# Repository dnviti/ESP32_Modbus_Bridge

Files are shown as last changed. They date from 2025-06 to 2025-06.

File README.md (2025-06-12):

# **Dual ESP32 Modbus TCP to Wi-Fi Bridge**

This repository contains the KiCad project files and design documentation for a custom PCB that acts as an industrial data bridge. The board reads data from a PLC via Modbus TCP over Ethernet and transmits it to a web server via Wi-Fi.

## **High-Level Functionality**

The board is designed around a dual-ESP32 architecture to handle network tasks concurrently and without interference:

* **ESP32 \#1 (Modbus Master):**  
  * Connects to an industrial network via a hardwired Ethernet (RJ45) port.  
  * Communicates with a PLC using the Modbus TCP protocol to read register values.  
  * Transfers the retrieved data internally to the second ESP32.  
* **ESP32 \#2 (Web Client):**  
  * Receives data from the first ESP32 via a high-speed UART link.  
  * Connects to a local Wi-Fi network.  
  * Formats and sends the data to a specified web server endpoint using HTTPS POST requests.  
  * Drives a small I2C OLED display for real-time status monitoring (e.g., IP address, connection status, last sync time).

## **Key Hardware Features**

* **Dual ESP32-WROOM-32D Sockets:** For parallel processing of networking tasks.  
* **Robust Power Supply:** On-board 24V to 3.3V DC-DC buck converter to draw power directly from a PLC or industrial power rail.  
* **Wired & Wireless Connectivity:** Features a Hanrun HR911105A RJ45 port for Ethernet and integrated Wi-Fi/Bluetooth on the ESP32s.  
* **On-Board Debugging:** Includes FTDI programming headers, manual boot/reset buttons, and debug jumpers with status LEDs for each ESP32.  
* **I/O & Expansion:** Provides breakout headers for unused GPIO pins for future expansion and an I2C header for the status display.  
* **High-Density Design:** Utilizes 0402 package size for passive components to maintain a small form factor.

## **Full Documentation**

This README provides a brief overview. For complete technical details, including the full schematic specification, component list, bill of materials (BOM), and PCB layout guidelines, please refer to the comprehensive design document:

➡️ View the Complete Design & Manufacturing Specification  
(Note: Replace the link above with the actual URL to your hosted specification document.)

## **Project Files**

* **/Hardware**: Contains the KiCad project files (.pro, .sch, .kicad\_pcb).  
* **/Documentation**: Contains the full design specification PDF and other supporting documents.  
* **/Firmware**: Contains example Arduino/ESP-IDF source code for both ESP32 modules.  
* **/Gerbers**: Contains the final manufacturing files for PCB fabrication.

*This project is designed for industrial applications where reliability and clear diagnostics are critical. Please review the full documentation before fabrication or assembly.*

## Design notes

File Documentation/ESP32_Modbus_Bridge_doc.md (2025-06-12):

# **Complete Design & Manufacturing Specification: Dual ESP32 Modbus-Wi-Fi Bridge**

Document Version: 2.3  
Date: June 12, 2025  
Project Revision: 0.1

## **1\. Schematic Design Specification**

This document provides the detailed, step-by-step connection instructions for creating the complete schematic for the Dual ESP32 Modbus-Wi-Fi Bridge, based on project revision 0.1.

### **1.1. Footprint Assignment**

Before proceeding to PCB layout, every component listed below must be assigned a correct physical footprint in the EDA software. An incorrect footprint will result in a board that cannot be assembled. The recommended footprints are provided for each component.

### **1.2. Part 1: Shared Board Components (The Foundation)**

This section details the main 24V to 3.3V power supply unit that powers the entire board.

**Component List:**

* **J1:** Conn\_Screw\_Terminal\_1x02 (Footprint: TerminalBlock:TerminalBlock\_bornier-2\_P5.08mm)  
* **U3:** LM2596S-3.3 (Footprint: Package\_TO\_SOT\_SMD:TO-263-5\_TabPin3)  
* **C2:** 100uF Electrolytic Capacitor (Footprint: Capacitor\_SMD:CP\_Elec\_6.3x5.4mm, verify voltage rating \> 24V)  
* **C1:** 220uF Electrolytic Capacitor (Footprint: Capacitor\_SMD:CP\_Elec\_8x10.5mm)  
* **D1:** D\_Schottky (1N5822 SMD equivalent) (Footprint: Diode\_SMD:D\_SMA)  
* **L1:** 33uH Inductor (Footprint: Inductor\_SMD:L\_Bourns\_SRR1260, verify current rating)  
* **D2:** LED (Footprint: LED\_SMD:LED\_0603\_1608Metric)  
* **R1:** 2.2kΩ Resistor (Footprint: Resistor\_SMD:R\_0603\_1608Metric)

**Connection Instructions:**

1. **24V Input:** Connect **Pin 1** of **J1** to a net named \+24V. Connect **Pin 2** of **J1** to the main GND net.  
2. **LM2596S-3.3 Input and Control:** Connect the \+24V net to **Pin 1 (VIN)** of **U3**. Place **C2** between the \+24V net and the GND net. Connect **Pin 3 (GND)** of **U3** to the GND net. Connect **Pin 5 (ON/OFF)** of **U3** directly to the GND net.  
3. **LM2596S-3.3 Output Circuit:** Connect the **Anode** of **D1** to the GND net. Connect the **Cathode** of **D1** to **Pin 2 (VOUT)** of **U3**. Connect one end of **L1** also to **Pin 2 (VOUT)** of **U3**. Connect the other end of **L1** to a new net named \+3.3V. Place **C1** between the \+3.3V net and the GND net.  
4. **Feedback Connection:** Connect **Pin 4 (Feedback)** of **U3** directly to the \+3.3V net.  
5. **Power Indicator LED:** Connect one end of **R1** to the \+3.3V net. Connect the other end of **R1** to the **Anode** of **D2**. Connect the **Cathode** of **D2** to the GND net.

### **1.3. Part 2: ESP32 \#1 (Modbus Master & Ethernet)**

**Component List:**

* **U1:** ESP32-WROOM-32D (Footprint: RF\_Module:ESP32-WROOM-32)  
* **U5:** LAN8720A (Footprint: Package\_QFN:QFN-24-1EP\_4x4mm\_P0.5mm\_EP2.6x2.6mm)  
* **Y1:** SG-7050CAN 50MHz (Footprint: Oscillator:Oscillator\_SMD\_5032-4Pin\_5.0x3.2mm)  
* **J5:** Hanrun HR911105A (Footprint: Connector\_RJ:RJ45\_Hanrun\_HR911105A\_Horizontal)  
* **J4:** Conn\_01x06\_Male (FTDI ESP32\#1) (Footprint: Connector\_PinHeader\_2.54mm:PinHeader\_1x06\_P2.54mm\_Vertical)  
* **SW1:** SW\_Push (U1\_BOOT) (Footprint: Button\_Switch\_SMD:SW\_SPST\_PTS645)  
* **C3, C4, C5, C6, C7, C8, C9, C10, C11:** Capacitors (See schematic for values and assign footprints like C\_0402, C\_0805)  
* **R2, R3, R4, R5, R6, R8, R9:** Resistors (See schematic for values and assign footprints like R\_0402)  
* **FB1:** Ferrite\_Bead (Footprint: Inductor\_SMD:L\_0603\_1608Metric)  
* **Debug Interface Components:** See Section 1.6.1  
* **GPIO Breakout Components:** See Section 1.7.1

**Connection Instructions:**

1. **ESP32 \#1 Power and Decoupling:** Connect the **VCC** and **GND** pins of **U1** to the \+3.3V and GND nets. Place **C3 (10uF)** and **C4 (100nF)** between VCC and GND, close to the module.  
2. **ESP32 \#1 Programming Header (FTDI):** Place **J4**. Connect its **GND** to GND, **TXD** to **GPIO3** of **U1**, and **RXD** to **GPIO1** of **U1**. Leave **VCC** and **CTS** unconnected.  
3. **ESP32 \#1 Auto-Reset and Manual Boot Circuit:** Connect a **100nF capacitor** between the **DTR pin** of **J4** and the **EN** pin of **U1**. Connect **R2 (10kΩ)** between the **EN** pin and \+3.3V. Connect **SW1** between the **GPIO0** pin of **U1** and GND. Connect **R3 (10kΩ)** between the **GPIO0** pin and \+3.3V.  
4. **ESP32 \#1 Strapping Pin:** Connect **R4 (10kΩ)** between the **GPIO12** pin of **U1** and GND.  
5. **Ethernet Sub-system (LAN8720A, Oscillator, RJ45):**  
   * **Clock Generation (Y1):** Connect the **VCC pin** of **Y1** to \+3.3V and place **C11 (100nF)** between this pin and GND. Connect the **ST pin** of **Y1** to \+3.3V. Connect the **GND pin** of **Y1** to GND. Connect the **OUT pin** of **Y1** to **Pin 5 (XTAL1/CLKIN)** of **U5**.  
   * **ESP32 to LAN8720A Interface:** Connect **Pin 14 (nINT/REFCLKO)** of **U5** to **GPIO0** of **U1**. Connect **GPIO23** of **U1** to **Pin 13 (MDC)** of **U5**. Connect **GPIO18** of **U1** to **Pin 12 (MDIO)** of **U5**. For RMII Transmit: U1 GPIO21 \-\> U5 Pin 16 (TXEN); U1 GPIO19 \-\> U5 Pin 17 (TXD0); U1 GPIO22 \-\> U5 Pin 18 (TXD1). For RMII Receive: U1 GPIO25 \<- U5 Pin 8 (RXD0); U1 GPIO26 \<- U5 Pin 7 (RXD1); U1 GPIO27 \<- U5 Pin 11 (CRS\_DV).  
   * **LAN8720A (U5) Support Circuitry:** Connect **R5 (12.1kΩ)** from **Pin 24 (RBIAS)** of **U5** to GND. Place **C7 (1uF)** and **C8 (470pF)** in parallel between **Pin 6 (VDDCR)** of **U5** and GND. For analog power filtering, connect the \+3.3V net to **FB1**, creating a \+3.3V\_Filtered net. Connect this filtered net to **Pin 1 (VDD2A)** and **Pin 19 (VDD1A)** of **U5**. Place **C10 (100nF)** from VDD2A to GND, and **C6 (100nF)** from VDD1A to GND.  
   * **RJ45 Jack (J5) and Termination:** For differential pairs: U5 Pin 21 (TXP) \-\> J5 Pin 1 (TD+); U5 Pin 20 (TXN) \-\> J5 Pin 2 (TD-); U5 Pin 23 (RXP) \-\> J5 Pin 3 (RD+); U5 Pin 22 (RXN) \-\> J5 Pin 6 (RD-). For DC bias, connect one side of all four **49.9Ω resistors (R6, R8, R9, and one more)** to the \+3.3V\_Filtered net, and connect the other side of each resistor individually to the PHY's differential pair pins (TXP, TXN, RXP, RXN). For center-tap termination, connect jack pins **4 (TCT)** and **5 (RCT)** together, then connect this node through **C9 (1000pF)** to a chassis ground point.

### **1.4. Part 3: ESP32 \#2 (Web Client)**

**Component List:**

* **U2:** ESP32-WROOM-32D (Footprint: RF\_Module:ESP32-WROOM-32)  
* **J2:** Conn\_01x06\_Male (FTDI ESP32\#2) (Footprint: Connector\_PinHeader\_2.54mm:PinHeader\_1x06\_P2.54mm\_Vertical)  
* **SW2:** SW\_Push (U2\_BOOT) (Footprint: Button\_Switch\_SMD:SW\_SPST\_PTS645)  
* **C13, C12, C14:** 10uF, 100nF, 100nF (Footprints: Capacitor\_SMD:C\_0805\_2012Metric, Capacitor\_SMD:C\_0402\_1005Metric)  
* **R10, R11, R12:** 10kΩ Resistors (Footprint: Resistor\_SMD:R\_0402\_1005Metric)  
* **Debug Interface Components:** See Section 1.6.2  
* **GPIO Breakout Components:** See Section 1.7.2

**Connection Instructions:**

1. **ESP32 \#2 Power and Decoupling:** Connect the **VCC** and **GND** pins of **U2** to the \+3.3V and GND nets. Place its dedicated **C13 (10uF)** and **C12 (100nF)** decoupling capacitors between its VCC and GND pins.  
2. **ESP32 \#2 Programming Header (FTDI):** Place **J2**. Connect its **GND** to GND, **TXD** to **GPIO3** of **U2**, and **RXD** to **GPIO1** of **U2**. Leave **VCC** and **CTS** unconnected.  
3. **ESP32 \#2 Auto-Reset and Manual Boot Circuit:** Connect **C14 (100nF)** between the **DTR pin** of **J2** and the **EN** pin of **U2**. Connect **R10 (10kΩ)** between the **EN** pin and \+3.3V. Connect **SW2** between the **GPIO0** pin of **U2** and GND. Connect **R11 (10kΩ)** between the **GPIO0** pin and \+3.3V.  
4. **ESP32 \#2 Strapping Pin:** Connect **R12 (10kΩ)** between the **GPIO12** pin of **U2** and GND.

### **1.5. Part 4: Inter-Module Communication**

* Connect the **GPIO17** pin of **ESP32 \#1 (U1)** to the **GPIO16** pin of **ESP32 \#2 (U2)**.  
* Connect the **GPIO16** pin of **ESP32 \#1 (U1)** to the **GPIO17** pin of **ESP32 \#2 (U2)**.

### **1.6. Part 5: I2C OLED Display Interface**

* **Component List:**  
  * **J11:** Conn\_01x04\_Male (I2C Connector) (Footprint: Connector\_PinHeader\_2.54mm:PinHeader\_1x04\_P2.54mm\_Vertical)  
  * **R13:** 4.7kΩ Resistor (Footprint: Resistor\_SMD:R\_0402\_1005Metric)  
  * **R18:** 4.7kΩ Resistor (Footprint: Resistor\_SMD:R\_0402\_1005Metric)  
* **Connection Instructions:**  
  1. **Display Connector (J11):** Connect **Pin 1 (GND)** to GND, **Pin 2 (VCC)** to \+3.3V, **Pin 3 (SCL)** to **GPIO22** of **U2**, and **Pin 4 (SDA)** to **GPIO21** of **U2**.  
  2. **I2C Pull-up Resistors:** Connect **R18** between the SCL line and \+3.3V. Connect **R13** between the SDA line and \+3.3V.

### **1.7. Part 6: Debug Interfaces**

#### **1.7.1. ESP32 \#1 Debug Interface**

* **Component List:**  
  * **J6:** Conn\_01x02\_Male (U1\_DEBUG) (Footprint: Connector\_PinHeader\_2.54mm:PinHeader\_1x02\_P2.54mm\_Vertical)  
  * **R16:** 10kΩ Resistor (Footprint: Resistor\_SMD:R\_0402\_1005Metric)  
  * **D4:** LED (Footprint: LED\_SMD:LED\_0402\_1005Metric)  
  * **Q2:** NPN Transistor (MMBT2222A) (Footprint: Package\_TO\_SOT\_SMD:SOT-23)  
  * **R14:** 1kΩ Resistor (Footprint: Resistor\_SMD:R\_0402\_1005Metric)  
  * **R17:** 4.7kΩ Resistor (Footprint: Resistor\_SMD:R\_0402\_1005Metric)  
* **Connection Instructions:**  
  1. **Debug Jumper:** Connect **Pin 1** of **J6** to \+3.3V, and **Pin 2** to **GPIO15** of **U1**.  
  2. **Pull-down Resistor:** Connect **R16** between **GPIO15** of **U1** and GND.  
  3. **LED Driver:** Connect **R14** between \+3.3V and the **Anode** of **D4**. Connect the **Cathode** of **D4** to the **Collector** of **Q2**. Connect the **Emitter** of **Q2** to GND. Connect **R17** between **GPIO15** of **U1** and the **Base** of **Q2**.

#### **1.7.2. ESP32 \#2 Debug Interface**

* **Component List:**  
  * **J9:** Conn\_01x02\_Male (U2\_DEBUG) (Footprint: Connector\_PinHeader\_2.54mm:PinHeader\_1x02\_P2.54mm\_Vertical)  
  * **R\_DBG2\_PD:** 10kΩ Resistor (Footprint: Resistor\_SMD:R\_0402\_1005Metric)  
  * **D3:** LED (Footprint: LED\_SMD:LED\_0402\_1005Metric)  
  * **Q1:** NPN Transistor (MMBT2222A) (Footprint: Package\_TO\_SOT\_SMD:SOT-23)  
  * **R\_DBG2\_LED:** 1kΩ Resistor (Footprint: Resistor\_SMD:R\_0402\_1005Metric)  
  * **R\_DBG2\_BASE:** 4.7kΩ Resistor (Footprint: Resistor\_SMD:R\_0402\_1005Metric)  
* **Connection Instructions:**  
  1. **Debug Jumper:** Connect **Pin 1** of **J9** to \+3.3V, and **Pin 2** to **GPIO13** of **U2**.  
  2. **Pull-down Resistor:** Connect R\_DBG2\_PD between **GPIO13** of **U2** and GND.  
  3. **LED Driver:** Connect R\_DBG2\_LED between \+3.3V and the **Anode** of **D3**. Connect the **Cathode** of **D3** to the **Collector** of **Q1**. Connect the **Emitter** of **Q1** to GND. Connect R\_DBG2\_BASE between **GPIO13** of **U2** and the **Base** of **Q1**.

### **1.8. Part 7: General Purpose I/O (GPIO) Breakouts**

#### **1.8.1. ESP32 \#1 GPIO Breakout**

* **Component List:**  
  * **J7 (GPIO\_EXT\_U1):** Conn\_02x05\_Male (Footprint: Connector\_PinHeader\_2.54mm:PinHeader\_2x05\_P2.54mm\_Vertical)  
* **Connection Instructions:**  
  * Connect **Pin 1** of **J7** to \+3.3V; **Pin 2** to GND.  
  * **J7 Pin 3:** U1 GPIO4  
  * **J7 Pin 4:** U1 GPIO5  
  * **J7 Pin 5:** U1 GPIO13  
  * **J7 Pin 6:** U1 GPIO14  
  * **J7 Pin 7:** U1 GPIO13  
  * **J7 Pin 8:** U1 GPIO32  
  * **J7 Pin 9:** U1 GPIO33  
  * **J7 Pin 10:** GND

#### **1.8.2. ESP32 \#2 GPIO Breakout**

* **Component List:**  
  * **J8 (GPIO\_EXT\_U2):** Conn\_02x08\_Male (Footprint: Connector\_PinHeader\_2.54mm:PinHeader\_2x08\_P2.54mm\_Vertical)  
* **Connection Instructions:**  
  * Connect **Pin 1** of **J8** to \+3.3V; **Pin 2** to GND.  
  * **J8 Pin 3:** U2 GPIO4  
  * **J8 Pin 4:** U2 GPIO5  
  * **J8 Pin 5:** U2 GPIO13  
  * **J8 Pin 6:** U2 GPIO14  
  * **J8 Pin 7:** U2 GPIO15  
  * **J8 Pin 8:** U2 GPIO18  
  * **J8 Pin 9:** U2 GPIO19  
  * **J8 Pin 10:** U2 GPIO23  
  * **J8 Pin 11:** U2 GPIO25  
  * **J8 Pin 12:** U2 GPIO26  
  * **J8 Pin 13:** U2 GPIO27  
  * **J8 Pin 14:** U2 GPIO32  
  * **J8 Pin 15:** U2 GPIO33  
  * **J8 Pin 16:** GND

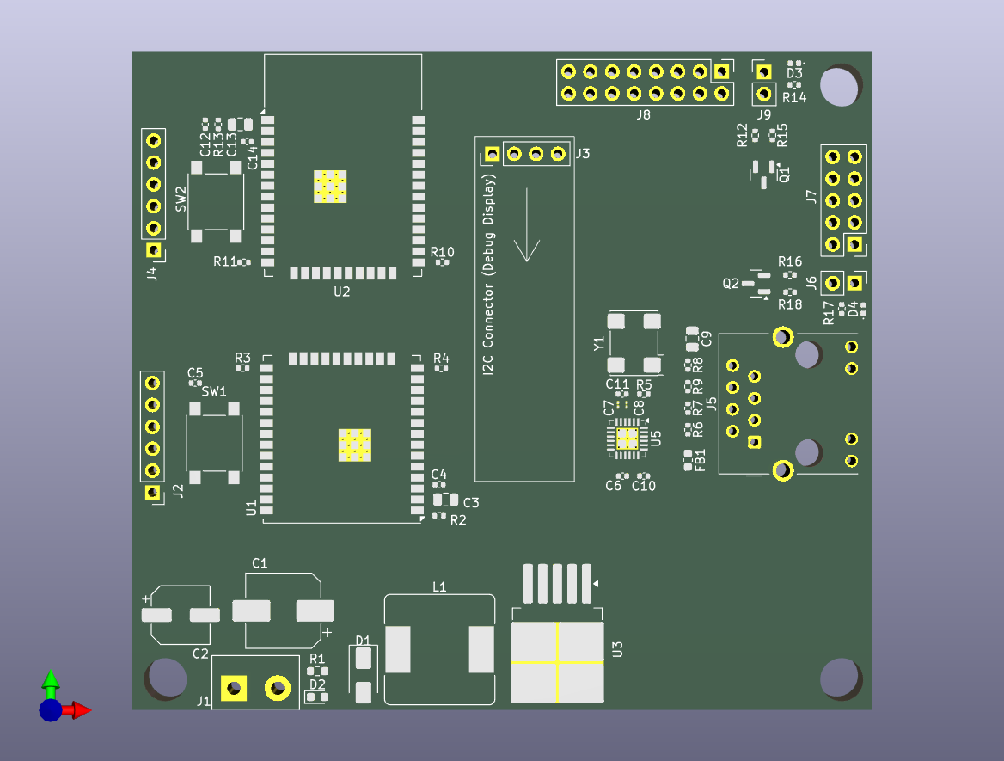
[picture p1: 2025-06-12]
Documentation/ESP32_Modbus_Bridge.png

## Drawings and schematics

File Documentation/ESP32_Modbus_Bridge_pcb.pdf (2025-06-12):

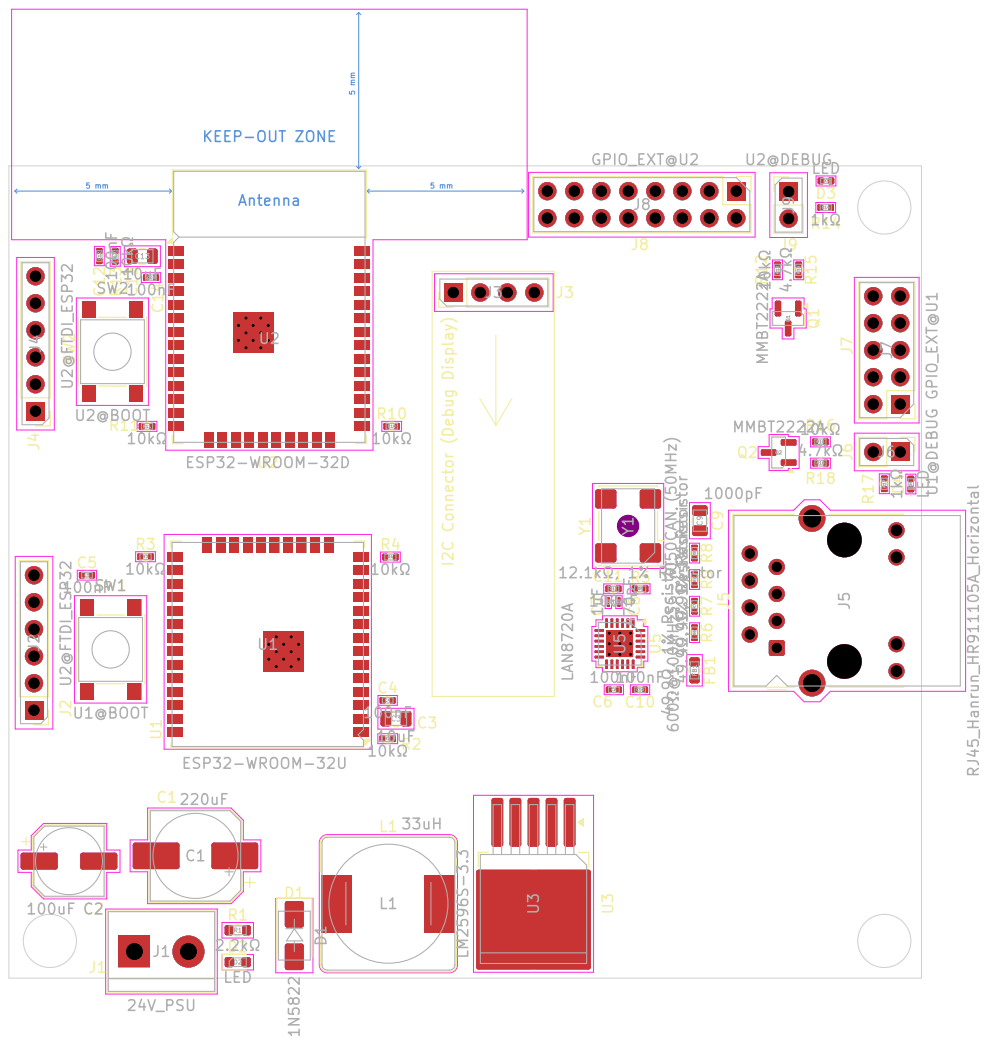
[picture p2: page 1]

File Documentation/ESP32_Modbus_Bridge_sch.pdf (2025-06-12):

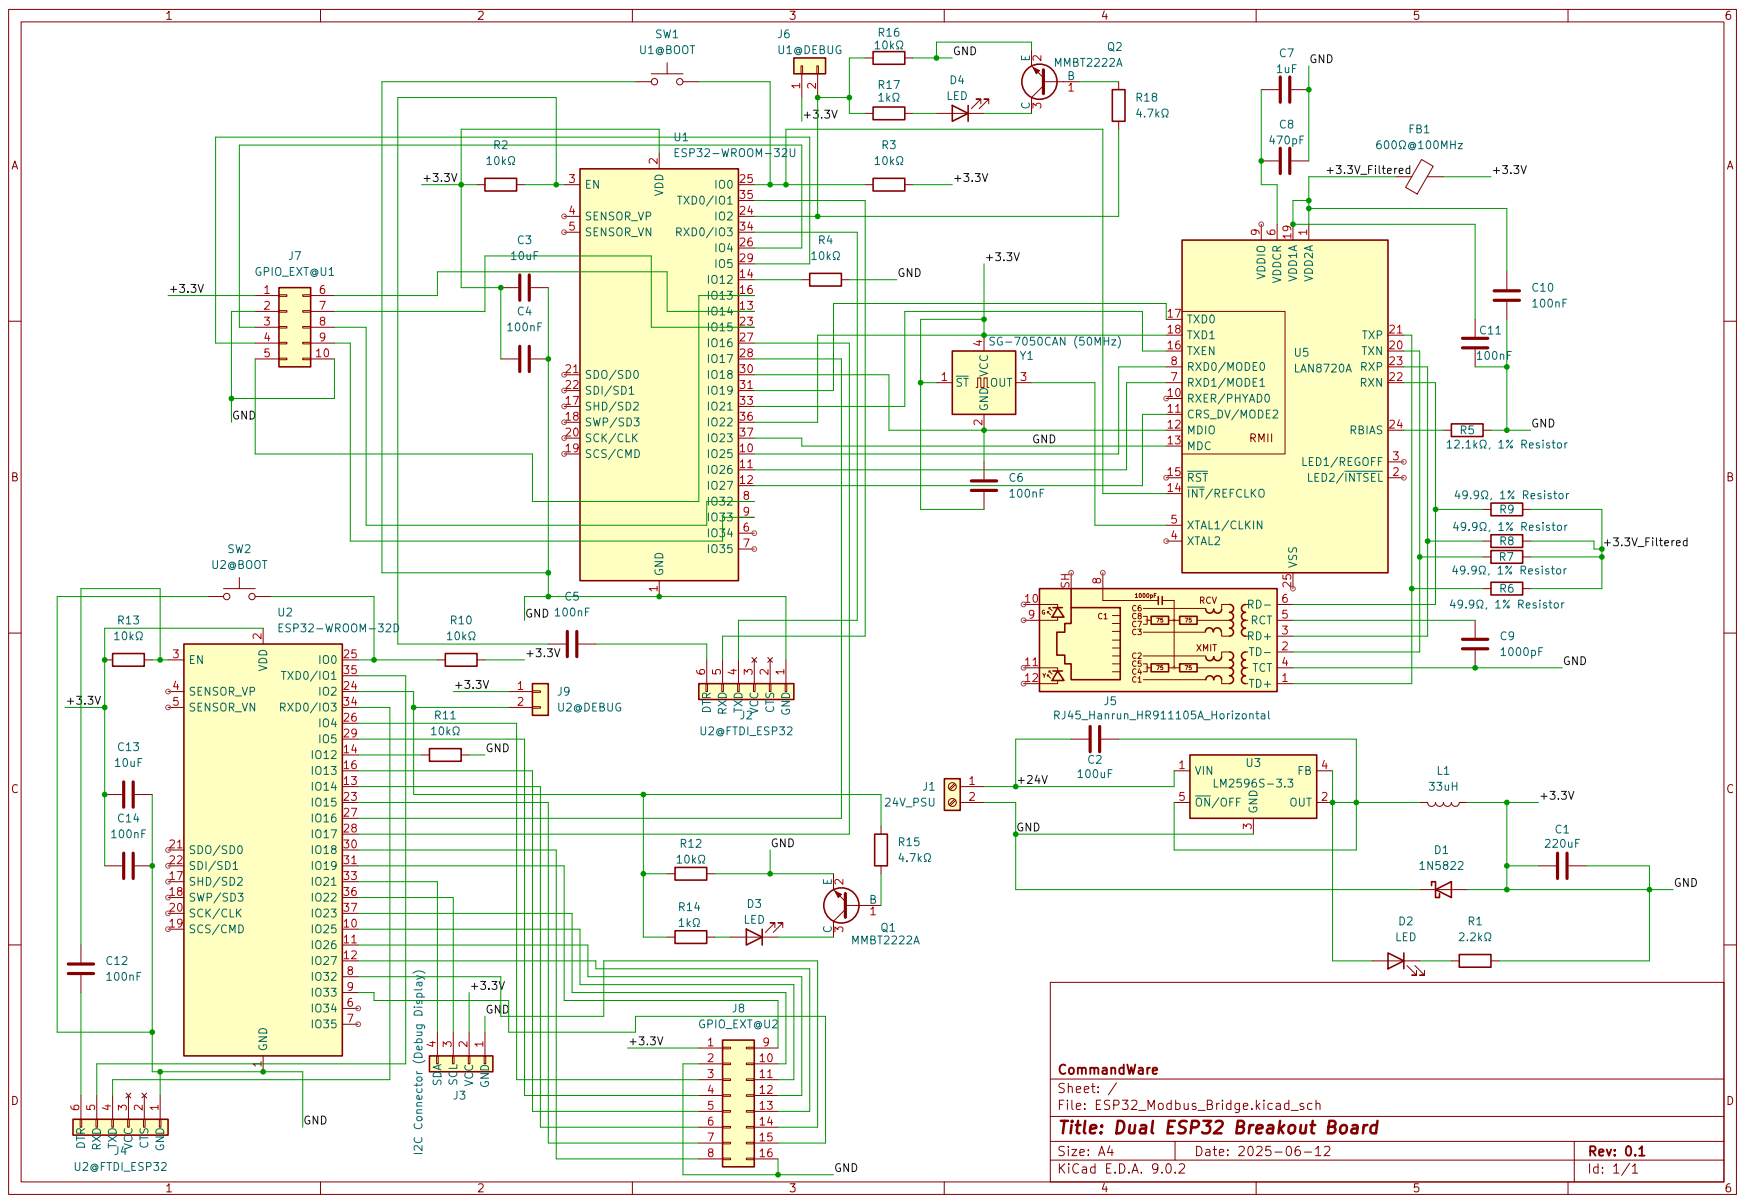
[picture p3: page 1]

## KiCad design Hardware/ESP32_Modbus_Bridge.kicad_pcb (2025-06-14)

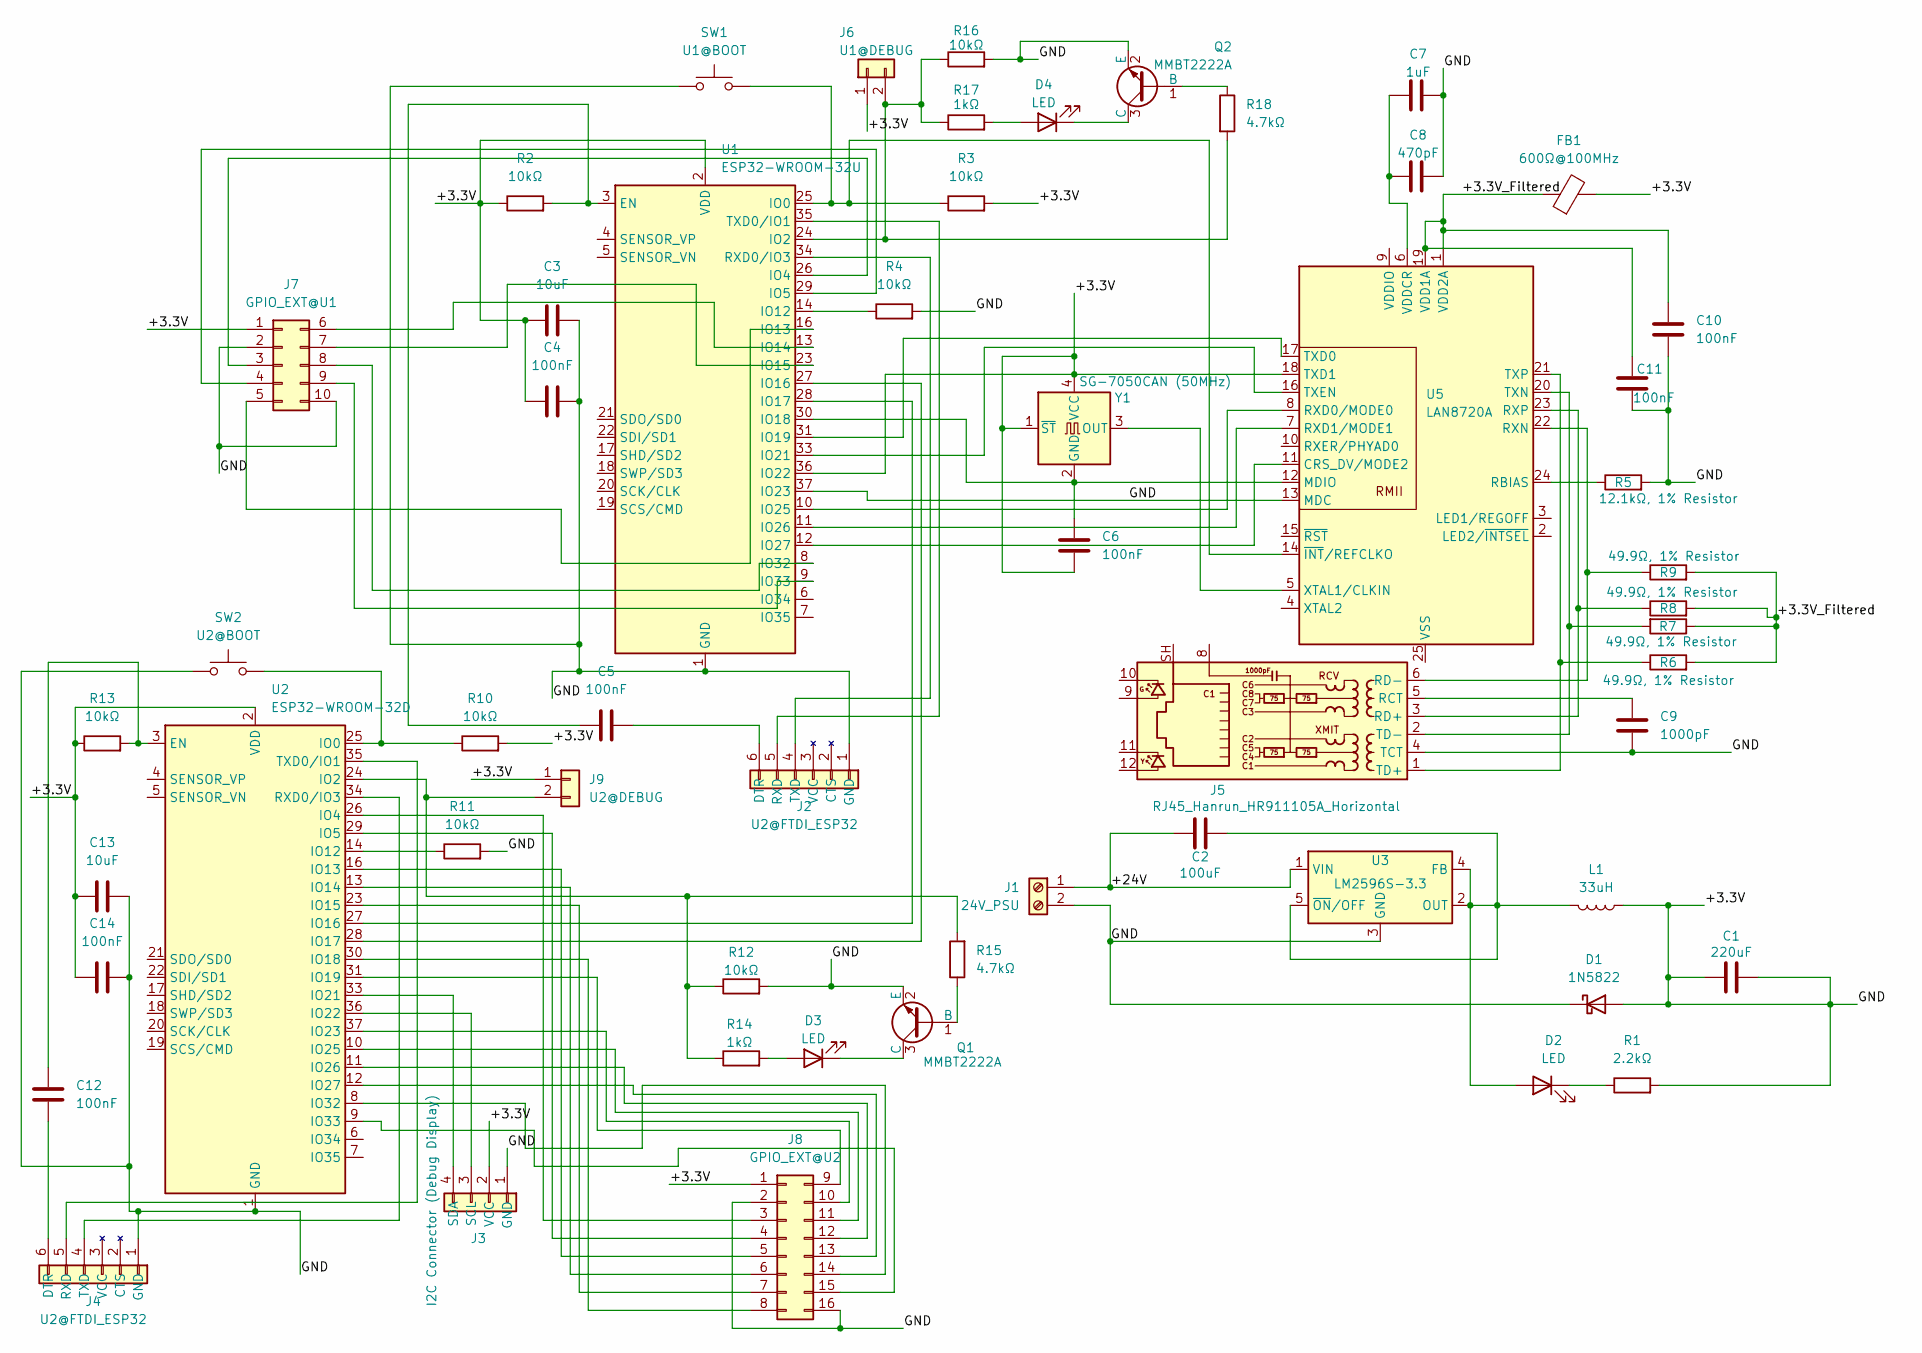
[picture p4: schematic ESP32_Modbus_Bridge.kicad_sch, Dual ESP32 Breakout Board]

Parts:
C1: 220uF; CP_Elec_8x10.5
C2: 100uF; CP_Elec_6.3x5.4
C3, C13: 10uF; C_0805_2012Metric
C4, C5, C6, C10, C11, C12, C14: 100nF; C_0402_1005Metric
C7: 1uF; C_01005_0402Metric
C8: 470pF; C_01005_0402Metric
C9: 1000pF; C_0805_2012Metric
D1: 1N5822; D_SMA
D2: LED; LED_0603_1608Metric
D3, D4: LED; LED_0402_1005Metric
FB1: 600Ω@100MHz; L_0603_1608Metric
J1: 24V_PSU; TerminalBlock_bornier-2_P5.08mm
J2, J4: U2@FTDI_ESP32; PinHeader_1x06_P2.54mm_Vertical
J3: I2C Connector (Debug Display); PinHeader_1x04_P2.54mm_Vertical
J5: RJ45_Hanrun_HR911105A_Horizontal
J6: U1@DEBUG; PinHeader_1x02_P2.54mm_Vertical
J7: GPIO_EXT@U1; PinHeader_2x05_P2.54mm_Vertical
J8: GPIO_EXT@U2; PinHeader_2x08_P2.54mm_Vertical
J9: U2@DEBUG; PinHeader_1x02_P2.54mm_Vertical
L1: 33uH; L_Bourns_SRR1260
Q1, Q2: MMBT2222A; SOT-23
R1: 2.2kΩ; R_0603_1608Metric
R2, R3, R4, R10, R11, R12, R13, R16: 10kΩ; R_0402_1005Metric
R5: 12.1kΩ, 1% Resistor; R_0402_1005Metric
R6, R7, R8, R9: 49.9Ω, 1% Resistor; R_0402_1005Metric
R14, R17: 1kΩ; R_0402_1005Metric
R15, R18: 4.7kΩ; R_0402_1005Metric
SW1: U1@BOOT; SW_SPST_PTS645
SW2: U2@BOOT; SW_SPST_PTS645
U1: ESP32-WROOM-32U
U2: ESP32-WROOM-32D
U3: LM2596S-3.3; TO-263-5_TabPin3
U5: LAN8720A; VQFN-24-1EP_4x4mm_P0.5mm_EP2.5x2.5mm_ThermalVias
Y1: SG-7050CAN (50MHz); Oscillator_SMD_SeikoEpson_SG8002CA-4Pin_7.0x5.0mm

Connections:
/+3.3V: C1.1, C1.2, C3.1, C3.2, C4.1, C4.2, C6.1, C7.2, C8.2, C9.1, C10.2, C11.2, C13.1, C13.2, C14.1, C14.2, D1.1 (K), D1.2 (A), FB1.2, J1.2, J2.1 (GND), J3.1 (GND), J3.2 (VCC), J4.1 (GND), J5.4 (TCT), J6.1, J7.1 (+3.3V), J7.2 (GND), J7.10 (GND), J8.1 (+3.3V), J8.2 (GND), J8.16 (GND), J9.1, L1.1, Q1.2 (E), Q2.2 (E), R1.2, R2.1, R3.2, R4.2, R5.2, R10.2, R11.2, R12.2, R13.1, R16.2, SW1.1, SW2.1, U1.1 (GND), U1.2 (VDD), U1.15 (GND), U1.36 (IO22), U1.37 (IO23), U1.38 (GND), U1.39 (GND), U2.1 (GND), U2.2 (VDD), U2.15 (GND), U2.38 (GND), U2.39 (GND), U3.3 (GND), U5.13 (MDC), U5.18 (TXD1), Y1.1 (~ST), Y1.4 (VCC)
/+3.3V_Filtered: C10.1, C11.1, FB1.1, R6.2, R7.1, R8.2, R9.2, U5.1 (VDD2A), U5.19 (VDD1A)
/+24V: C2.1, J1.1, U3.1 (VIN)
unnamed: C2.2, D2.2 (A), L1.2, U3.2 (OUT), U3.4 (FB), U3.5 (~ON/OFF)
unnamed: D2.1 (K), R1.1
unnamed: D3.2 (A), R14.2
unnamed: D3.1 (K), Q1.3 (C)
unnamed: D4.2 (A), R17.2
unnamed: D4.1 (K), Q2.3 (C)
unnamed: C5.2, J2.6 (DTR)
unnamed: J2.5 (RXD), U1.35 (TXD0/IO1)
unnamed: J2.4 (TXD), U1.34 (RXD0/IO3)
unnamed: J3.3 (SCL), U2.36 (IO22)
unnamed: J3.4 (SDA), U2.33 (IO21)
unnamed: C12.1, J4.6 (DTR)
unnamed: J4.5 (RXD), U2.35 (TXD0/IO1)
unnamed: J4.4 (TXD), U2.34 (RXD0/IO3)
unnamed: C9.2, J5.5 (RCT)
unnamed: J5.3 (RD+), R8.1, U5.23 (RXP)
unnamed: J5.6 (RD-), R9.1, U5.22 (RXN)
unnamed: J5.1 (TD+), R6.1, U5.21 (TXP)
unnamed: J5.2 (TD-), R7.2, U5.20 (TXN)
unnamed: J6.2, R16.1, R17.1, R18.2, U1.24 (IO2)
unnamed: J7.3 (GPIO4), U1.26 (IO4)
unnamed: J7.4 (GPIO5), U1.29 (IO5)
unnamed: J7.5 (GPIO13), U1.16 (IO13)
unnamed: J7.6 (GPIO14), U1.13 (IO14)
unnamed: J7.7 (GPIO15), U1.23 (IO15)
unnamed: J7.8 (GPIO32), U1.8 (IO32)
unnamed: J7.9 (GPIO33), U1.9 (IO33)
unnamed: J8.3 (P4), U2.26 (IO4)
unnamed: J8.4 (P5), U2.29 (IO5)
unnamed: J8.5 (P13), U2.16 (IO13)
unnamed: J8.6 (P14), U2.13 (IO14)
unnamed: J8.7 (P15), U2.23 (IO15)
unnamed: J8.8 (P18), U2.30 (IO18)
unnamed: J8.9 (P19), U2.31 (IO19)
unnamed: J8.10 (P23), U2.37 (IO23)
unnamed: J8.11 (P25), U2.10 (IO25)
unnamed: J8.12 (P26), U2.11 (IO26)
unnamed: J8.13 (P27), U2.12 (IO27)
unnamed: J8.14 (P32), U2.8 (IO32)
unnamed: J8.15 (P33), U2.9 (IO33)
unnamed: J9.2, R12.1, R14.1, R15.2, U2.24 (IO2)
unnamed: Q1.1 (B), R15.1
unnamed: Q2.1 (B), R18.1
unnamed: C5.1, R2.2, U1.3 (EN)
unnamed: R3.1, SW1.2, U1.25 (IO0), U5.14 (~INT/REFCLKO)
unnamed: R4.1, U1.14 (IO12)
unnamed: U1.27 (IO16), U2.28 (IO17)
unnamed: U1.28 (IO17), U2.27 (IO16)
unnamed: C6.2, U1.30 (IO18), U5.12 (MDIO), Y1.2 (GND)
unnamed: U1.31 (IO19), U5.17 (TXD0)
unnamed: U1.33 (IO21), U5.16 (TXEN)
unnamed: U1.10 (IO25), U5.8 (RXD0/MODE0)
unnamed: U1.11 (IO26), U5.7 (RXD1/MODE1)
unnamed: U1.12 (IO27), U5.11 (CRS_DV/MODE2)
unnamed: C12.2, R13.2, U2.3 (EN)
unnamed: R10.1, SW2.2, U2.25 (IO0)
unnamed: R11.1, U2.14 (IO12)
unnamed: R5.1, U5.24 (RBIAS)
unnamed: C7.1, C8.1, U5.6 (VDDCR)
unnamed: U5.5 (XTAL1/CLKIN), Y1.3 (OUT)

Board: 4 copper layers, 56 parts (0 on the bottom side), 63 nets, no tracks yet.

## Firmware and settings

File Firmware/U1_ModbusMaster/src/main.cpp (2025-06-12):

#include <Arduino.h>

// put function declarations here:
int myFunction(int, int);

void setup() {
  // put your setup code here, to run once:
  int result = myFunction(2, 3);
}

void loop() {
  // put your main code here, to run repeatedly:
}

// put function definitions here:
int myFunction(int x, int y) {
  return x + y;
}
